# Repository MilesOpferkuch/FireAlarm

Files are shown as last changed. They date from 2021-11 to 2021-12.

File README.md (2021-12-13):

# FireAlarm

#### A WiFi-enabled fire alarm for use with a Raspberry Pi, ESP32 and MQ-2 smoke detector chip.

**Demonstration:** https://www.youtube.com/watch?v=HQU86N-uDGA

**Explanation:**
I made this to feel safer when leaving my 3D printer running overnight. The Raspberry Pi reads the output pin of an MQ-2 smoke detector chip. When it detects smoke, its output goes to 0 volts. The Raspberry Pi then sets off an alarm connected directly to it, and sets off another alarm via WiFi. That WiFi alarm runs on an ESP32 microcontroller and can be put anywhere in the house, as long as they're both on the same WiFi network.

Directories:
- **/3D files/** -- 3D printable files for the electronics enclosures
- **/esp32/** -- Contains the Python script for the ESP32
- **/gerber/** -- Contains the Gerber files for the circuit board
- **/media/** -- Pictures of the schematics and PCBs
- **/rPi/** -- Contains the Python script for the Raspberry Pi

Raspberry Pi circuit:
Raspberry Pi circuit

Raspberry Pi circuit PCB:
Raspberry Pi circuit PCB

ESP32 circuit:
ESP32 circuit

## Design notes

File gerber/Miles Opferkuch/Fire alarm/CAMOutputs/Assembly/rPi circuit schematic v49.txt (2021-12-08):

Partlist exported from Team Hub: Miles Opferkuch   Project: Fire alarm  Board: rPi circuit schematic v49 at 12/7/2021 9:35 PM

Qty Value            Device                          Package               Parts         Description                                                   CATEGORY   DESCRIPTION                                                                          IC_MAX MANUFACTURER          MPN        OPERATING_TEMP OPERATING_TEMPERATURE PART_STATUS PROD_ID   PROD_ID_ALT ROHS_COMPLIANCE ROHS_COMPLIANT SERIES   SUB-CATEGORY SUBCATEGORY    SUB_CATEGORY           THERMALLOSS TYPE             VALUE   VCEO_MAX
1                    BUZZER_CE-C75                   BUZZER_CE-C75         U$3                                                                                                                                                                                                                                                                                                                                                                                                                                
1   100k             100KOHM-HORIZ-1/4W-5%           AXIAL-0.3             R2            100kΩ resistor                                                                                                                                                                                                                                         RES-10686                                                                                                                                     100k            
1   10k              10KOHM-HORIZ-1/4W-5%            AXIAL-0.3             R1            10kΩ resistor                                                                                                                                                                                                                                          RES-09435                                                                                                                                     10k             
1   10uF             10UF-POLAR-RADIAL-2.5MM-25V-20% CPOL-RADIAL-2.5MM-5MM C1            10.0µF polarized capacitors                                                                                                                                                                                                                            CAP-08440                                                                                                                                     10uF            
3   1k               1KOHM-HORIZ-1/4W-5%             AXIAL-0.3             R3, R5, R6    1kΩ resistor                                                                                                                                                                                                                                           RES-08380                                                                                                                                     1k              
3   2828XX-2282837-2 2828XX-2282837-2                TERMBLK_508-2N        U$1, U$2, U$4 2 Position Wire to Board Terminal Block Horizontal with Board Connector    2 Position Wire to Board Terminal Block Horizontal with Board 5.08 mm Through Hole        TE Connectivity       282837-2                  -40°C to +105°C       ACTIVE                            RoHS Compliant                 282837                Terminal Block                                     Side Wire Entry                 
1   2N2222A          NPN_JAN2N2222A_TO18             TO18                  Q1            NPN - Popular parts                                           Transistor TRANS NPN 50V 0.8A                                                                   800mA  Microsemi Corporation JAN2N2222A -65°C ~ 200°C                        Active                                            Yes                     BJT                                                500mW       NPN              2N2222A 50V     
1   330              330OHM-HORIZ-1/10W-5%           AXIAL-0.3             R4            330Ω resistor                                                                                                                                                                                                                                          RES-8371                                                                                                                                      330             
1   3A/250V          B2B-XH-A                        B2B-XH-A              J2            XH Connector Top Entry - 2POS                                 CONNECTOR  2.5mm pitch/disconnectable crimp style connector                                            JST (XH CONNECTOR)    B2B-XH-A                  -25°C ~ 85°C          ACTIVE                                            COMPLIANT      B_B-XH-A                             Through hole connector             top entry        3A/250V         
1   3A/250V          B3B-XH-A                        B3B-XH-A              J1            XH Connector Top Entry - 3POS                                 CONNECTOR  2.5mm pitch/disconnectable crimp style connector                                            JST (XH connector)    B3B-XH-A                                        ACTIVE                                            COMPLIANT      B3B-XH-A                             THROUGH HOLE CONNECTOR             SIDE ENTRY       3A/250V         
1   555              555P                            DIP08                 IC1           General purpose bipolar Timer                                                                                                                                                                                                                          IC-09173  IC-09173                                                                                                                            555

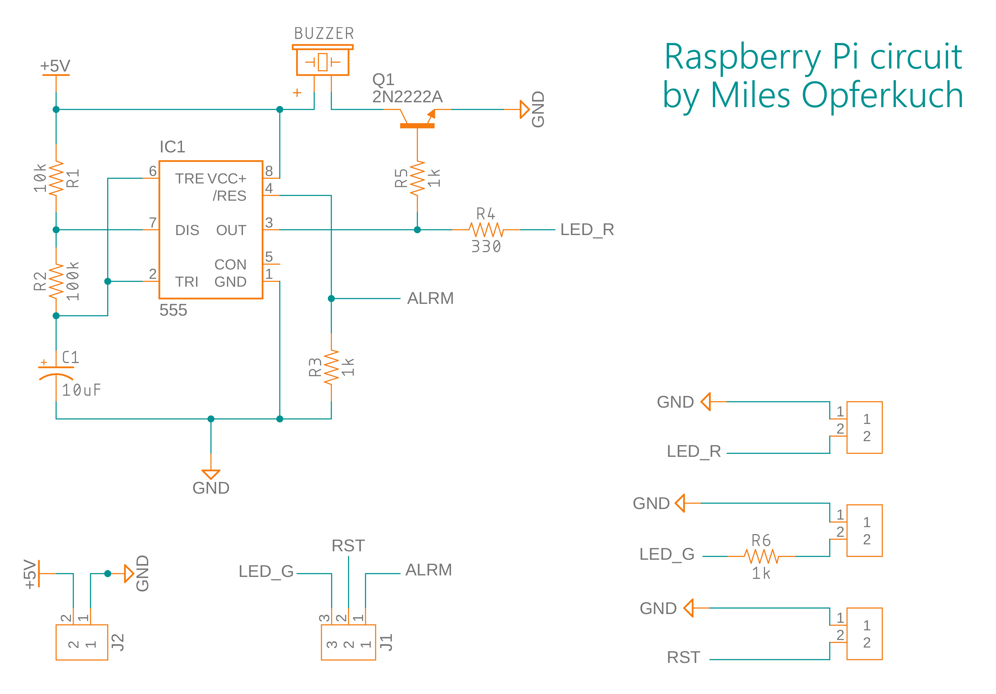
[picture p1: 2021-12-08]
media/rPi_schem.png

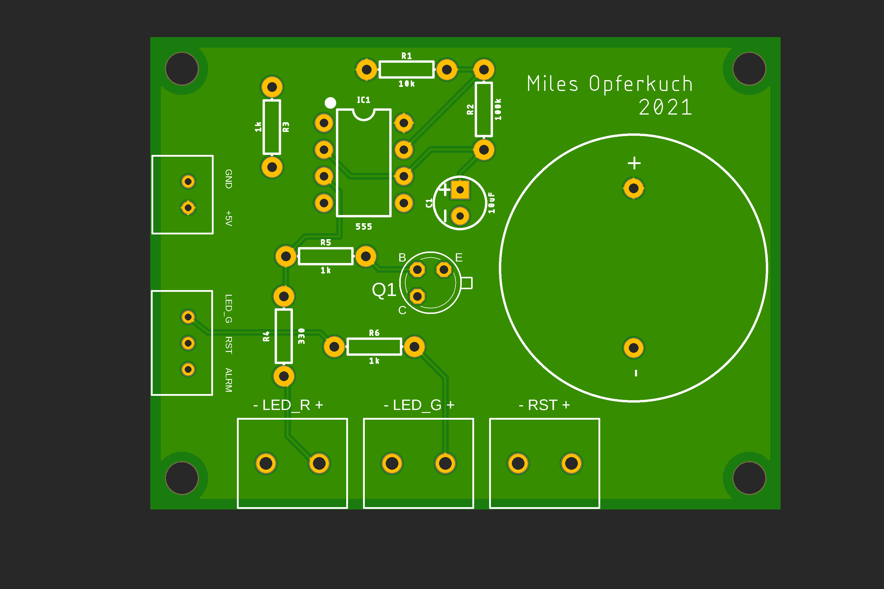
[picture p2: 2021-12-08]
media/rPi_PCB.png

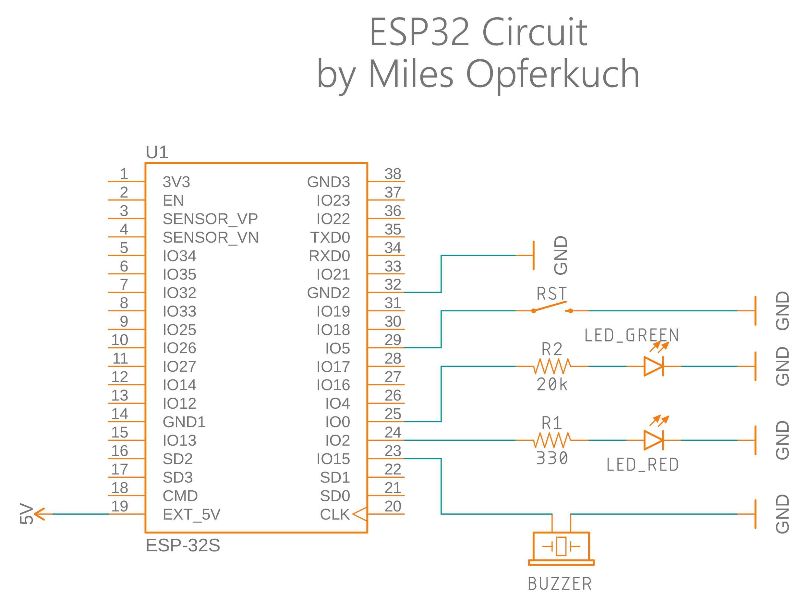
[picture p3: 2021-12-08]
media/ESP32_schem.png

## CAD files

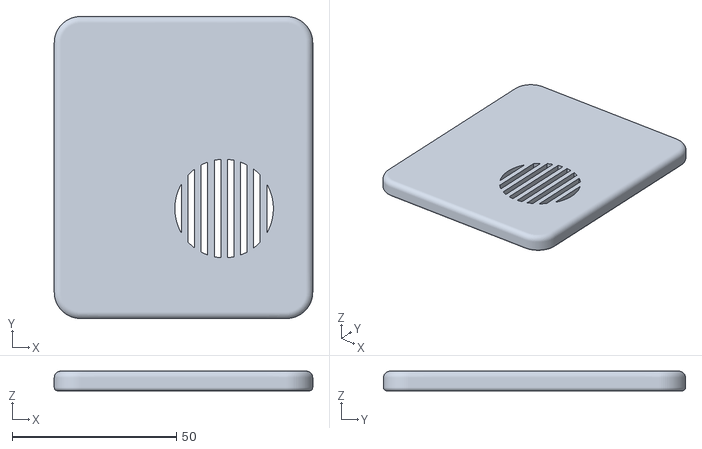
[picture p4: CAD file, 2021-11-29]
3D files/esp32_enclosure_lid.stl
78.8 x 92.0 x 6.00

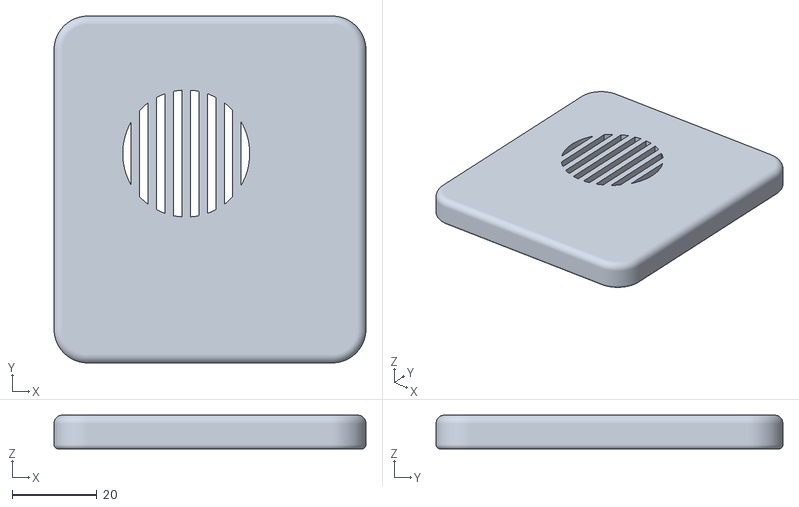
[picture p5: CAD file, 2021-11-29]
3D files/rpi alarm enclosure lid.stl
73.8 x 82.0 x 8.00

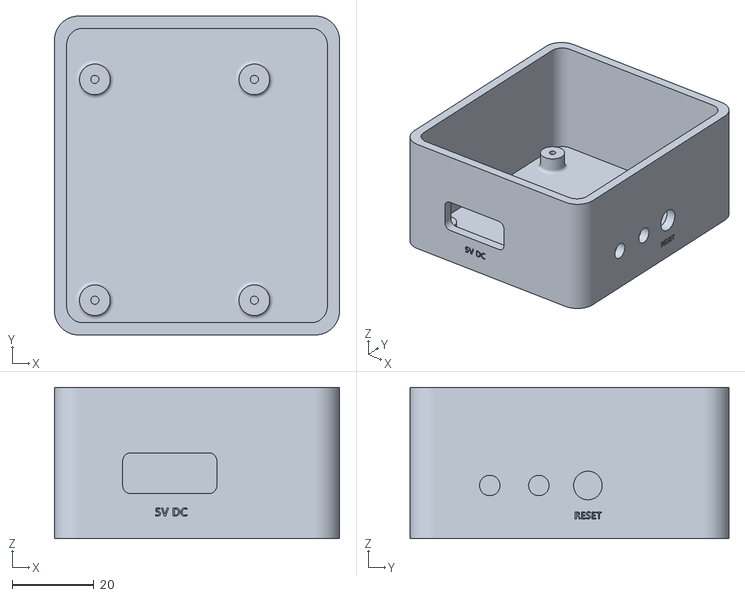
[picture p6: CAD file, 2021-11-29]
3D files/rpi alarm enclosure.stl
69.8 x 78.0 x 37.0

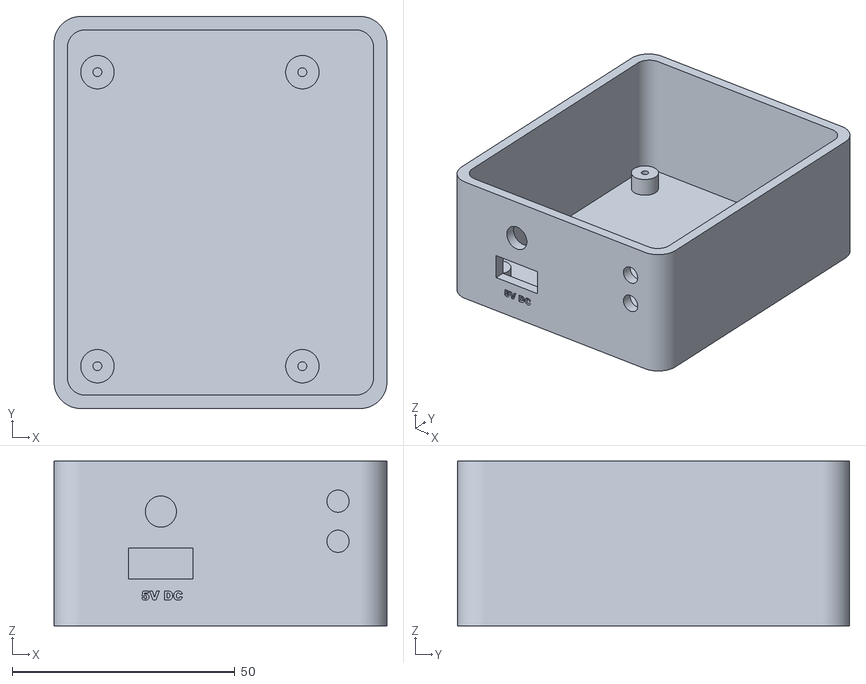
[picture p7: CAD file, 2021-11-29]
3D files/esp32_enclosure.stl
74.8 x 88.0 x 37.0

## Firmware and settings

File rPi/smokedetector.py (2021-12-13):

import requests
import time
import datetime
import RPi.GPIO as GPIO
import socket
import sys
from multiprocessing import Process

GPIO.setmode(GPIO.BCM)

'''
Final project: WiFi smoke detector by Miles Opferkuch
https://github.com/MilesOpferkuch/FireAlarm

This script will run on a Raspberry Pi in my garage, which sits next to my 3D printer
and runs OctoPrint. It reads from a MQ-2 smoke detector circuit, which normally outputs 3.3v
but drops to low voltage when there's smoke. This script sets off an alarm in the garage,
sends a push notification to my phone, and sends a signal to an ESP32 microprocessor in my bedroom
which has its own alarm. That way I'll hear it if I'm sleeping. In subsequent comments, "local alarm" refers to
the one in the garage (controlled by this script) and "remote alarm" refers to the one in my bedroom (controlled by /esp32/boot.py).
'''


# Print message with local timestamp
def print_t(msg):
    timestamp = time.strftime("%Y-%m-%d %H:%M:%S", time.localtime())
    tz = datetime.datetime.now(datetime.timezone.utc).astimezone().tzname()
    if tz == "Pacific Standard Time":
        tz = "PST"
    elif tz == "Pacific Daylight Time":
        tz = "PDT"
    print(f'[{timestamp} {tz}] {msg}')



class Server:

    def __init__(self, port):
        self.port = port
        self.alarmIsOn = False
        self.cooldownFlag = False           # Will be set True when RST button is pressed. This will disable the alarm for 5 minutes.
        self.cooldownTime = 0.0             # Epoch time when the RST button was last pressed.

        # Get IFTTT API key
        iftttFile = open('ifttt.txt')
        self.IFTTT_KEY = iftttFile.read().strip()
        iftttFile.close()


    # Pings the esp32 and waits for a response every 30 secs.
    # Sends a push notification if it times out. This runs as a subprocess.
    def getEspStatus(self, client):
        self.hasSentTimeoutNotif = False
        print_t("Started querying ESP32 status.")
        while True:
            try:
                client.send('STATUS\n'.encode())  # Ping esp32
                try:
                    data = client.recv(32)      # Wait for response
                    if data:
                        print_t("Received %s from esp32" % data.decode())
                        self.hasSentTimeoutNotif = False    # reset the notification flag
                # If we don't get a response, send push notif if we haven't already done so
                except socket.timeout:  
                    if not self.hasSentTimeoutNotif:
                        print_t("Esp32 status query timed out after 10 seconds, sending push notification...")
                        requests.post('https://maker.ifttt.com/trigger/esp_timeout/with/key/%s' % self.IFTTT_KEY)
                        self.hasSentTimeoutNotif = True
                        print_t("Push notification sent.")
                    else:
                        print_t("Esp32 status query timed out after 10 seconds. Already sent push notification.")
                time.sleep(30)
            except Exception as e:
                print("Could not query esp32's status: ", e)


    # Turn on local alarm.
    # The alarm runs on a 555 timer so all we have to do here is pull the ALRM pin high:
    # https://github.com/MilesOpferkuch/FireAlarm/blob/main/media/rPi_schem.png
    def alarmOn(self):
        if not self.cooldownFlag:
            GPIO.output(PIN_ALARM, 1)   
            self.alarmIsOn = True
            print_t("alarmOn() called!")


    # Turn off local alarm
    def alarmOff(self):
        GPIO.output(PIN_ALARM, 0)
        self.alarmIsOn = False
        print_t("alarmOff() called")


    def main(self):

        print_t("Starting server on port %d..." % self.port)
        sock = socket.socket(socket.AF_INET, socket.SOCK_STREAM)
        sock.setsockopt(socket.SOL_SOCKET, socket.SO_REUSEADDR, 1)      # Fixes "address already in use" error
        sock.bind(('', self.port))
        sock.listen(MAX_CLIENTS)
        print_t("Server started. Waiting for client to connect.")

        client, cl_addr = sock.accept()
        client.settimeout(10)
        print_t("Client %s:%d connected." % cl_addr)

        # Blink green light to indicate successful connection
        for i in range (0, 4):
            GPIO.output(PIN_LED_GREEN, 0)
            time.sleep(0.1)
            GPIO.output(PIN_LED_GREEN, 1)
            time.sleep(0.1)

        # Start pinging esp32
        queryProcess = Process(target=self.getEspStatus, args=(client,))
        queryProcess.start()

        # Main loop
        while True:
            # Trigger the local alarm if the MQ2 pin goes low.
            # The local alarm is fired by pulling PIN_ALARM high.
            # It runs on a 555 timer so we don't have to block the main thread by turning the buzzer on and off.
            if (GPIO.input(PIN_MQ2) == 0
                and not self.alarmIsOn
                and not self.cooldownFlag):

                time.sleep(0.25)    # 250ms debounce

                if GPIO.input(PIN_MQ2) == 0:
                    self.alarmIsOn = True
                    self.alarmOn()
                    print_t("Smoke detected! Stopping ESP32 status queries...")
                    if queryProcess.is_alive():
                        queryProcess.terminate()

                    # Send 'DOALARM' to esp32 to trigger the remote alarm.
                    print_t("Starting remote alarm: Sending signal...")
                    client.send('DOALARM\n'.encode())
                    print_t("Signal sent.")

                    # Send push notification to phone via IFTTT.
                    print_t("Sending push notification...")
                    requests.post('https://maker.ifttt.com/trigger/smoke_detected/with/key/%s' % self.IFTTT_KEY)
                    print_t("Notification sent.")

            # Handle reset button press
            if GPIO.input(PIN_RST) == 0 and self.alarmIsOn:
                print_t("RESET pressed. Pausing alarm for 5 minutes.")
                self.alarmOff()
                self.cooldownFlag = True
                self.cooldownTime = time.time()     # Take note of when we paused the alarm so we can un-pause it in 5 mins
                client.send("ALARMOFF\n".encode())      # Tell esp32 to stop its alarm
                queryProcess = Process(target=self.getEspStatus, args=(client,))    # Restart esp32 query process
                queryProcess.start()

            # Reset cooldown flag 5 minutes after RST button pressed
            if (time.time() >= self.cooldownTime + 300 and self.cooldownFlag):      
                self.cooldownFlag = False
                print_t("5 minutes since RESET pressed. Re-enabling alarm.")

            # Turn off alarm if MQ2 goes high again
            if self.alarmIsOn and GPIO.input(PIN_MQ2) == 1:
                print_t("MQ-2 reading high again; turning off alarm.")
                self.alarmOff()
                # Tell esp32 to stop its alarm
                client.send("ALARMOFF\n".encode())
                # Restart esp32 query process
                queryProcess = Process(target=self.getEspStatus, args=(client,))
                queryProcess.start()


if __name__ == '__main__':
    server = Server(5678)
    MAX_CLIENTS = 1
    PIN_MQ2 = 24
    PIN_ALARM = 23
    PIN_LED_GREEN = 12
    PIN_RST = 25

    # Set up GPIO pins
    GPIO.setup(PIN_ALARM, GPIO.OUT)
    GPIO.setup(PIN_LED_GREEN, GPIO.OUT)
    GPIO.setup(PIN_MQ2, GPIO.IN, pull_up_down=GPIO.PUD_DOWN)
    GPIO.setup(PIN_RST, GPIO.IN, pull_up_down=GPIO.PUD_UP)
    # Start server with outputs low
    GPIO.output(PIN_ALARM, 0)
    GPIO.output(PIN_LED_GREEN, 0)

    # Run server
    try:
        server.main()
    except KeyboardInterrupt:
        GPIO.output(PIN_ALARM, 0)
        GPIO.output(PIN_LED_GREEN, 0)
        GPIO.cleanup
        sys.exit(0)
    except Exception as e:
        print_t(e)

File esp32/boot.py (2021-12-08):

import network
import webrepl
import machine
import errno
import time
from time import localtime
from ntptime import settime
import socket
import urequests

'''
Final project: WiFi smoke detector by Miles Opferkuch
https://github.com/MilesOpferkuch/FireAlarm

This script runs on the ESP32 microprocessor in my bedroom. It receives data
from the Raspberry Pi in my garage, and sets off an alarm when it receives the signal to do so.
Note that this uses Micropython and will only run on an ESP32 (or possibly an ESP8266).
It's also specific to how my circuit is wired: https://github.com/MilesOpferkuch/FireAlarm/blob/main/media/ESP32_schem.png
'''


# Set up GPIO pins
PIN_ALARM = machine.Pin(15, machine.Pin.OUT)                   # Pin to piezo buzzer
PIN_LED_RED = machine.Pin(2, machine.Pin.OUT)                  # Pin to red status light
PIN_LED_GREEN = machine.Pin(0, machine.Pin.OUT)                # Pin to green status light
PIN_RST = machine.Pin(5, machine.Pin.IN, machine.Pin.PULL_UP)  # Pin to reset button

# Pull low on startup
PIN_ALARM.value(0)
PIN_LED_RED.value(0)
PIN_LED_GREEN.value(0)

# The time we last received a ping from RPi.
# If this exceeds 40 seconds, the connection is dead and we send a push notification.
lastPingTime = 0.0

hasSentPushNotif = False

# Get IFTTT API key
iftttFile = open('ifttt.txt')
IFTTT_KEY = iftttFile.read().strip()
iftttFile.close()

# Get WiFi credentials
credfile = open('wifi.txt')
SSID, PWD = str.splitlines(credfile.read())
credfile.close()

# Prints messages with a UTC timestamp. Micropython lacks a lot of
# Python's datetime formatting stuff so we have to do it manually.
def print_t(msg):
    # localtime() returns a tuple so I convert it to a list for formatting.
    # Despite the name, it's actually in UTC.
    time = list(localtime())
    # Zero-padding
    for i in range (0, len(time)):
        if len(time[i]) == 1:
            time[i] = "0" + time[i]
    # [yyyy-MM-dd HH:mm:ss UTC]
    print(f'[{time[0]}-{time[1]}-{time[2]} {time[3]}:{time[4]}:{time[5]} UTC] {msg}')


# Make error codes human-readable
def errorName(e):
    errorName = "???"
    try:
        errorName = errno.errorcode[e.errno]
    except:
        pass
    return errorName


# Connect to WiFi
def wifi_connect():
    sta_if = network.WLAN(network.STA_IF)
    if not sta_if.isconnected():
        print('Connecting to network %s...' % SSID)
        sta_if.active(True)
        sta_if.connect(SSID, PWD)
        while not sta_if.isconnected():
            PIN_LED_RED.value(1)
            PIN_LED_GREEN.value(1)
            pass
    print('Connected to WiFi. Network config:', sta_if.ifconfig())

    # Set clock
    try:
        settime()
    except OSError:
        print("Error getting time from remote server. Log timestamps will be incorrect.")
    rtc = machine.RTC()
    print_t("System clock set.")

    PIN_LED_RED.value(0)
    # Blink green LED to indicate successful connection to router
    for i in range(0,4):
        time.sleep(0.2)
        PIN_LED_GREEN.value(1)
        time.sleep(0.2)
        PIN_LED_GREEN.value(0)

isConnectedToWifi = False
try:
    wifi_connect()
    isConnectedToWifi = True
except OSError as e:
    PIN_LED_RED.value(1)
    print(f"Could not connect to {SSID}: error code {str(e.errno)} [{errorName(e)}].\nTrying again in 5 seconds.")

webrepl.start()

# Connect to RPi and retry if it fails
def server_connect(host, port):
    isConnectedToPi = False
    while not isConnectedToPi:
        try:
            print_t("Connecting to %s:%d..." % (host, port))
            sock = socket.socket(socket.AF_INET, socket.SOCK_STREAM)
            sock.connect((host, port))
            isConnectedToPi = True
        except OSError as e:
            sock.close()
            PIN_LED_RED.value(1)
            print_t(f"Connection to RPi failed: error code {str(e.errno)} [{errorName(e)}].\nTrying again in 5 seconds.")
            time.sleep(5)
    print_t("Connection established.")
    PIN_LED_RED.value(0)
    PIN_LED_GREEN.value(1)
    return sock

# Set up client
def client(host, port):

    doAlarm = False
    sock = server_connect(host, port)

    # Callback for reset button IRQ
    def rst_callback(pin):
        nonlocal doAlarm
        doAlarm = False
        PIN_LED_RED.value(0)
        PIN_ALARM.value(0)
        print_t("Reset button pressed. Local alarm turned off.")

    # Set up CPU interrupt for reset button.
    # This is on an interrupt so it works even while the thread is blocked.
    PIN_RST.irq(trigger=machine.Pin.IRQ_FALLING, handler=rst_callback)

    # Main loop
    while True:

        data = sock.recv(512).decode().splitlines()     # Listen for data from RPi

        # Fire the alarm if we get the signal from RPi
        if 'DOALARM' in data:
            print_t("Alarm triggered!")
            sock.settimeout(1)
            doAlarm = True
            while doAlarm:
                # Listen for ALARMOFF signal from RPi
                try:
                    print_t("Listening for data...")
                    data = sock.recv(512).decode().splitlines()
                    if "ALARMOFF" in data:
                        doAlarm = False
                        sock.settimeout(None)
                        print_t("Alarm turned off by RPi")
                        break
                except:     # MicroPython doesn't like it if we catch socket.timeout specifically
                    pass
                # Blink LED and buzzer
                PIN_ALARM.value(1)
                PIN_LED_RED.value(1)
                time.sleep(1)
                PIN_ALARM.value(0)
                PIN_LED_RED.value(0)
                # No need to sleep here, the network timeout is 1 second

        # 'STATUS' should be sent by RPi every 30 seconds.
        # if esp32 fails to respond with 'CONNECTED', RPi sends a phone notification.
        if 'STATUS' in data:
            lastPingTime = time.time()
            hasSentPushNotif = False
            sock.send('CONNECTED'.encode())
            print_t("Status OK")
            PIN_LED_GREEN.value(1)
            PIN_LED_RED.value(0)

        # Send notification if 40 seconds have passed since the last ping from RPi
        if (time.time() > lastPingTime + 40 and not hasSentPushNotif):
            PIN_LED_RED.value(1)
            print_t("Lost connection to RPi! Sending push notification...")
            notif = urequests.post('https://maker.ifttt.com/trigger/rpi_timeout/with/key/%s' % IFTTT_KEY)
            notif.close()
            print_t("Push notification sent.")
            hasSentPushNotif = True

            sock.close()    # Close the old socket
            sock = server_connect(host, port)   # Try to make a new one

    sock.close()
    print_t("Client closed.")
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

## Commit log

2021-11-10 Fixed bugs on rpi
    [smokedetector.py]
2021-11-11 RPi: made alarm and ESP query run on separate threads; fixed hella shit
    [smokedetector.py]
2021-11-11 esp32: now listens for ALARMOFF signal from RPi
2021-11-11 RPi: switched alarm to a system interrupt which sets the gpio pin high; will be used to enable 555 timer. also added newline termination to data
2021-11-11 Fixed incoming data from RPi getting smashed together
    [boot.py]
2021-11-11 esp32: added interrupt for reset pin
2021-11-11 esp32: set output pins low on startup
2021-11-11 RPi: set output pins low on startup; turn off esp32 alarm when mq-2 goes high
2021-11-13 esp32: added timestamp to log messages; changed pins
2021-11-18 Added LED_GREEN pin
2021-11-18 Added gerber files
    [copper_bottom.gbr, copper_top.gbr, drill_1_16.xln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]
2021-11-29 Added STLs for enclosures
    [esp32_enclosure.stl, esp32_enclosure_lid.stl, rpi alarm enclosure lid.stl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]
2021-12-03 esp32: Fixed reset pin, added error handling to settime
    [boot.py]
2021-12-03 RPi: Fixed KeyboardInterrupt not cleaning up pins; added 250ms debounce to MQ2 pin
    [smokedetector.py]
2021-12-08 Updated gerber files
    [copper_bottom.gbr, copper_top.gbr, drill_1_16.xln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]
2021-12-08 esp32: added comments, cleaned up code, added more error handling
    [boot.py]
